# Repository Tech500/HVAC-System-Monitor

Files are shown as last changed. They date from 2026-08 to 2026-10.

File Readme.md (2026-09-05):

# HVAC System Monitor 

This repository contains a three‑node HVAC monitoring system designed as the successor to the Heating System Monitor IV project. It uses:

- LoRa Wake‑On‑Radio (WOR) for outdoor sensing
- ESP‑NOW for node‑to‑node communication
- Google Sheets for perpetual month‑to‑month and year‑to‑year logging

How blower detection works (variance-based thresholding): Blower state is detected with an MPU-6050 6-axis IMU attached to the outside of the blower enclosure. The sketch computes the statistical variance of accelerometer samples over a short window. A running blower produces mechanical vibration (high variance); a stopped blower produces almost none (low variance). Hysteresis between the ON and OFF thresholds prevents chatter at the transitions. No electrical hookup to the heating/cooling system is required, and no microphone is involved — it is immune to room noise.<br>

Logged data includes: NTP timestamp, outside temperature, inside temperature, inside humidity, thermostat setpoint, elapsed blower minutes (per cycle), daily total blower minutes, outside pressure, inside pressure, pressure difference (out − in), cycles today, coast minutes (hold time between cycles), and average cycle minutes.
Each record is written to both a local LittleFS log file and a perpetual Google Sheet (month-to-month, year-to-year).<br>

## Nodes

1. **WOR Sensor Node (Outdoor BME280)**  
   - SX1262 LoRa WOR RX  
   - BME280 outdoor readings  
   - ESP‑NOW TX → Receiver Node  

2. **Receiver Node (Indoor BME280 + Data collector + Google Sheets)**  
   - ESP‑NOW TX/RX (outdoor BME280 Node + Blower Node)  
   - Indoor BME280 readings  
   - Initiates WOR wake cycle  
   - Uploads combined HVAC data to Google Sheets  

3. **Blower Node (MPU6050 Vibration Sensing)**  
   - Detects blower ON/OFF via variance threshold, vibration  
   - ESP‑NOW TX → Receiver Node  
   - No electrical hookup to HVAC wiring
  
## Schematics and PCB Designs
The Schematics/ folder contains all hardware design files for the three‑node HVAC System Monitor.
All boards were designed in KiCad 10, and each PCB includes:

Full schematic (.kicad_sch)

PCB layout (.kicad_pcb)

Fabrication outputs (Gerber + drill files)

3D board previews (where applicable)

Supported Hardware Platforms
All PCBs in this project are designed around two specific ESP32‑S3 platforms:

Ebyte EoRa‑S3‑900TB  
A compact, battery‑optimized ESP32‑S3 + SX1262 LoRa module used for the WOR outdoor node and indoor receiver node.
Includes onboard battery charger, dual LDOs, SD slot, OLED header, and SX1262 radio — ideal for ultra‑low‑power sensing.

ESP32‑S3 SuperMini  
A minimal ESP32‑S3 module used for the Blower Node.
Provides a small footprint, simple power domain, and reliable ESP‑NOW performance for vibration sensing.

PCB Overview
The HVAC System Monitor requires three PCBs, corresponding to the three nodes:

ESP-NOW BME280 Node; with Wake-On-Radio (WOR) preamble (LoRa WOR + BME280)

ESP-NOW Indoor Node (BME280 + ESP‑NOW aggregator + Google Sheets uploader)

ESP-NOW Blower Node (MPU6050 vibration sensing + ESP‑NOW)

The ESP-NOW BME280 Node and ESP-NOW Inside Node use the same ESP‑NOW/BME280 PCB with GY-BME280-3.3V, 6 pin, built around the EoRa‑S3‑900TB.

The Blower Node uses a dedicated PCB built around the ESP32‑S3 SuperMini and the MPU6050 IMU.  
Note: not all ESP32-S3 SuperMini clones have the same pin layout!!!

PCB Designs Included
ESP-NOW BME280 Node and ESP‑NOW Blower Node

Single PCB design used for both ESP-NOW BME280 Node and ESP-NOW Inside Nodees

SX1262 LoRa WOR support (via EoRa-S3-900TB onboard SX1262 radio)

BME280 I²C header for GY-BME280-3.3V, 6 pin

EoRa-S3-900TB Battery‑optimized power domain

ESP‑NOW antenna layout

Mounting holes for outdoor enclosure use

ESP32‑S3 SuperMini Blower Node PCB

MPU6050 vibration sensor header

Vibration‑optimized mounting pattern

Simple 3.3V regulation

ESP‑NOW antenna layout

Compact footprint for blower, cabinet housing attachment
Note:  No electrical hook uprequired!

Fabrication Status
Gerber and drill files for all boards are included and ready for manufacturing.
The first batch of PCBs has been submitted and is currently awaiting delivery for hardware verification, fit‑testing, and firmware bring‑up.

## Folder Structure

```text
HVAC_System_Monitor/
│
├── BME280_Outside Node/
│   ├── BME280_WOR_Node.ino
│   ├── boards.h
│   ├── utilities.h
│   └── sx1262_commands.h
│  
│   
│
├── ESP-NOW_Inside_Node/
│   ├──  ESP-NOW_Inside_Node.ino  uses RadioLib library
|   ├── boards.h
│   └── utilities.h
│   
│
└── ESP-NOW_Blower_MPU6050/
    └──  ESP-NOW Blower_MPU6050ino

---

## Google Apps Script Setup

1. In Google Sheets, create a new Google Sheet.
2. Note the **Sheet ID** from the URL:
   `https://docs.google.com/spreadsheets/d/`**`<YOUR_SHEET_ID>`**`/edit`
3. Open the Script Editor: **Extensions → Apps Script**.
4. Delete the default `myFunction()` stub entirely.
5. Copy the full text contents of `Code.gs` from this repository.
6. Paste into the Script Editor.
7. Replace the placeholder Sheet ID in the script with the Sheet ID noted in Step 2.
8. **Save** (Ctrl+S or the save icon).
9. Click **Deploy → New Deployment**.
10. Select type: **Web App**.
11. Set **Execute as:** Me.
12. Set **Who has access:** Anyone.
13. Click **Authorize** → **Advanced** → click your Gmail account → **Allow**.
14. Copy the deployment ID and paste it into the Receiver sketch as the Google Script endpoint.

> **Note:** If you redeploy after changes, create a **New Deployment** each time and update
> the deployment ID in the Receiver sketch to match. (Editing an existing deployment to a
> new version can preserve the ID, but a fresh deployment always works.)

Numeric fields pass through a `numOrText()` helper in `Code.gs`: numbers are stored as
numbers, and the receiver's "Offline" sentinel (sent when the outdoor node fails to reply)
is preserved as text. Sheets functions like AVERAGE skip text cells automatically; in
pandas, load with `na_values=['Offline']`.

---

## Acknowledgements

This project was the result of a collaborative engineering effort involving both hands-on
experimentation and AI-assisted development. Each AI assistant contributed in different ways
throughout the project.

- **Claude** – Lead AI for all aspects of the project. Helped maintain technical focus,
  reviewed the evolving documentation for clarity and consistency, and provided extensive
  assistance in coding, organizing, and refining the final Markdown documentation.

- **Google Gemini** – Provided valuable guidance during the migration to **ESP32 Arduino
  Core 3.3.10**, helping identify and avoid legacy code patterns from earlier ESP32 core
  releases. Gemini also contributed to development discussions involving SX1262
  **Channel Activity Detection (CAD)**, Wake-on-Radio (WOR), and ESP32-S3 Deep Sleep
  integration.

- **ChatGPT** – Assisted throughout firmware development, debugging, architecture
  discussions, RadioLib integration, power optimization, Nordic PPK2 measurement
  interpretation, battery-life analysis, and technical review of the final documentation.

- **GitHub Copilot** – Assisted with firmware implementation, code completion, and
  day-to-day development within the programming environment.

- **Jan Gromeš** – Special thanks for the outstanding **RadioLib** library!

The successful implementation of an ESP32-S3 Deep Sleeping Wake-on-Radio node using the
SX1262 and RadioLib was made possible through this collaborative process. While the hardware
design, firmware integration, measurements, testing, and final engineering decisions were
performed by the author, the insights provided by each AI assistant significantly accelerated
development and helped improve the quality and accuracy of the final project.

*"Project not possible without everyone's help."*

## License

MIT License — see `LICENSE` for details.

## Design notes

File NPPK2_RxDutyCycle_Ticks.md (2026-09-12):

# SX1262 SetRxDutyCycle — Nordic PPK2 rxDutyCycle tick Observations

Power-profiling notes for `SetRxDutyCycle` (rxPeriod / sleepPeriod, in 15.625 µs ticks) on the SX1262, captured with a Nordic PPK2. 
Three experiment Images below, one per tick configuration tested.

### Nordic PPK II Observation Image 01

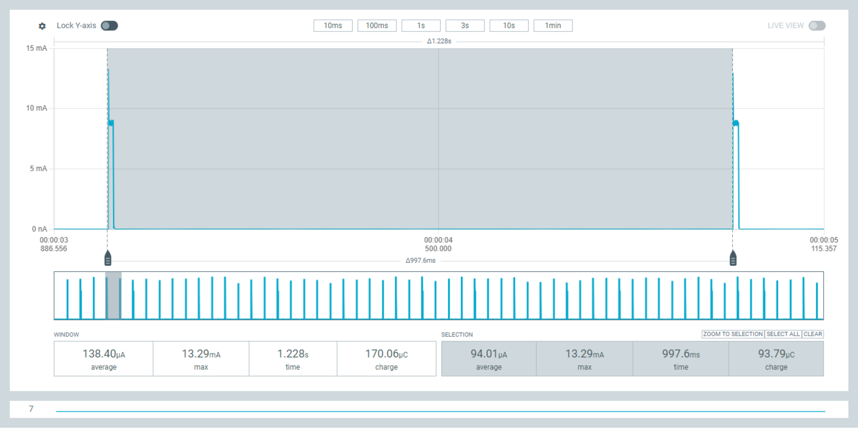
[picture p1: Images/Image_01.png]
Nordic PPK II --OneDutyCycle 01


#define RXDC_RX_TICKS       512UL  
#define RXDC_SLEEP_TICKS  63488UL  

| Metric | Value |
|---|---|
| Sleep average current | 22.40 µA |
| Duty-cycle average current | 94.01 µA |
| Peak current (RX window) | 13.29 mA |
| Wake event duration | 8.0 ms (per programmed rxPeriod) |
| Estimated battery life (3000 mAh) | ~43.7 months |

### Observations

- Selection window 997.6 ms, matching the programmed 1.000 s full cycle (8.0 ms RX + 992.0 ms sleep)
- By far the most efficient config measured — ~27× lower average current than Image 02, at the cost of a longer worst-case wake latency

---

### Nordic PPK II Observation Image 02

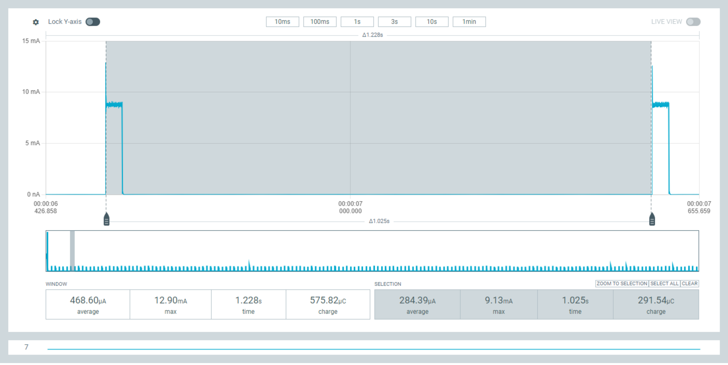
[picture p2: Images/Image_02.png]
Nordic PPK2 Observaton --OneDutyCycle 02


### Measurements

#define RXDC_RX_TICKS       2048UL  
#define RXDC_SLEEP_TICKS   64000UL  

| Metric | Value |
|---|---|
| Sleep average current | 21.94 µA  |
| Duty-cycle average current | 284.39 µA |
| Peak current (RX window) | 9.13 mA |
| Wake event duration | 32.0 ms (per programmed rxPeriod) |
| Estimated battery life (3000 mAh) | ~14.4 months |

### Observations

- Selection window 1.025 s, close to the programmed 1.032 s full cycle (32.0 ms RX + 1000.0 ms sleep)

---

### Nordic PPK II Observation Image 03

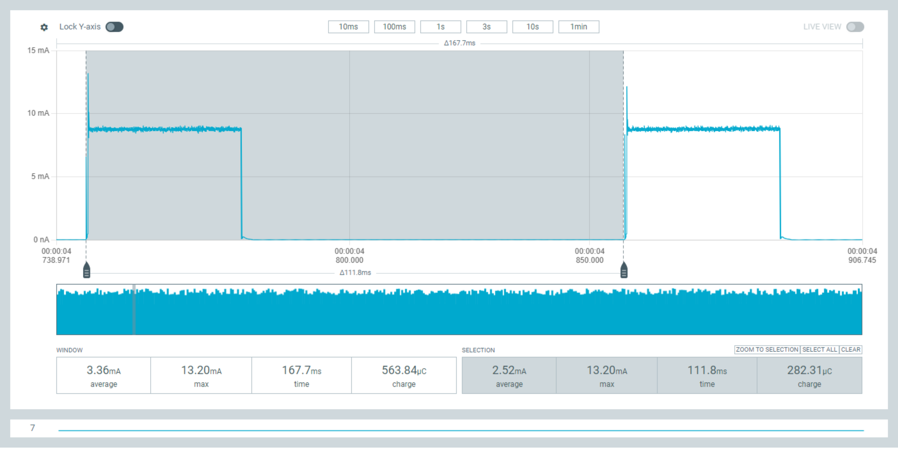
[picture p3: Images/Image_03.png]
Nordic PPK2 Observaton --OneDutyCycle 03


### Measurements

#define RXDC_RX_TICKS          1050UL  
#define RXDC_SLEEP_TICKS    5120UL  

| Metric | Value |
|---|---|
| Sleep floor current | ____ µA (not resolvable at this zoom level) |
| Duty-cycle average current | 2.52 mA |
| Peak current (RX window) | 13.20 mA |
| Wake event duration | 32.0 ms (per programmed rxPeriod) |
| Estimated battery life (3000 mAh) | ~1.6 months |

### Observations

- Selection window 111.8 ms, closely matching the programmed 112.0 ms full cycle (32.0 ms RX + 80.0 ms sleep)
- High average current (2.52 mA) driven by the 28.6% RX duty cycle — as expected, this is the least efficient config of the sweep

---

## Summary Comparison

| Image | Ticks (rxPeriod / sleepPeriod) | Duty-cycle avg (µA) | Est. battery life |
|---|---|---|---|
| 01 | 512 / 63488 | 94.01 | ~43.7 months |
| 02 | 2048 / 64000 | 284.39 | ~14.4 months |
| 03 |2048 / 5120 | 2520 | ~1.6 months |

### Conclusion

- Sleep period is the dominant lever, not RX period: Image 03 keeps the same 32 ms RX window as Image 02 but stretches sleep from 80 ms to 1000 ms, cutting average current ~9× (2520 µA → 284 µA)
- Shrinking the RX window matters too: Image 01 cuts RX from 32 ms to 8 ms on top of a comparable ~1 s sleep period, taking average current down another ~3× versus Image 03 (284 µA → 94 µA)
- Combined effect across the sweep so far: ~27× reduction in average current (2520 µA → 94 µA) and a projected battery-life improvement from ~1.6 months to ~43.7 months on a 3000 mAh cell
- Peak RX current stays roughly flat (9–13 mA) across all three configs — the gains come entirely from duty-cycle shaping, not from reducing per-window draw

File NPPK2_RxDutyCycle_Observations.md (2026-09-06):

# NPPK2 RxDutyCycle Observations — HVAC System Monitor (Outside Node)

Nordic PPK2 current captures of the outside node's register-level `SetRxDutyCycle` WOR cycle, including power-on init and a full WOR wake/transmit period.

## Power-On / EoRa Pi Init

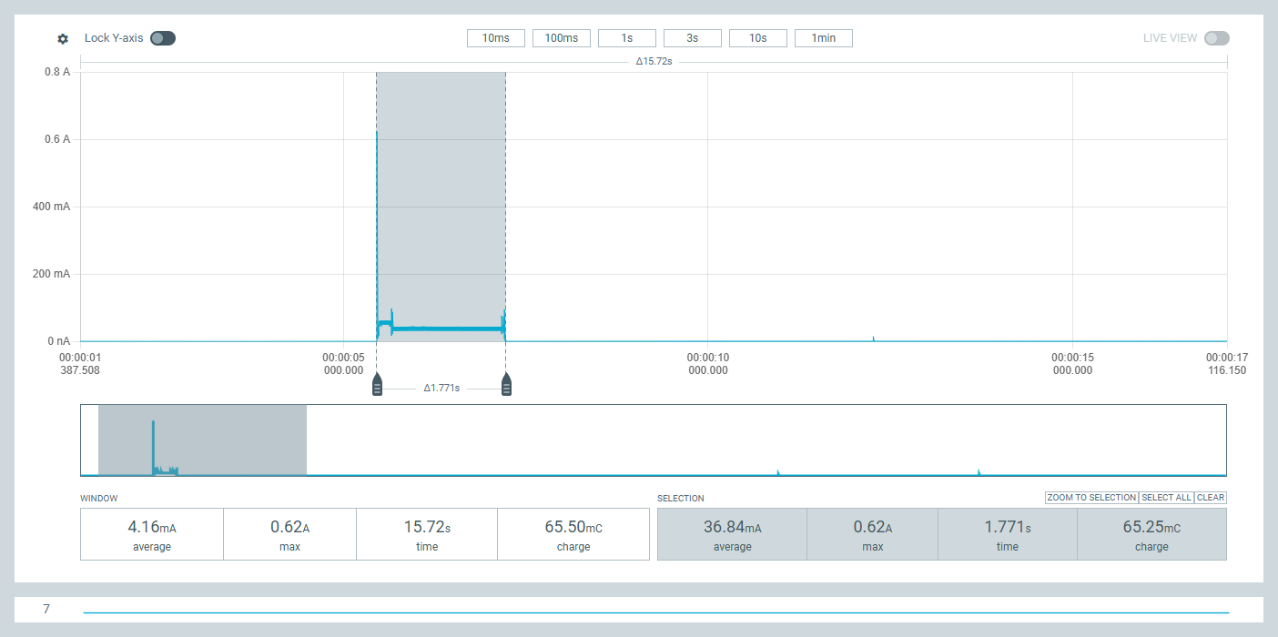
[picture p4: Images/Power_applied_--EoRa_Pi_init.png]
Power applied — EoRa-S3-900TB init
  

Capture from power application through radio/module initialization.

| Metric | Window (15.72 s) | Selection (1.771 s) |
|---|---|---|
| Average | 4.16 mA | 36.84 mA |
| Max | 0.62 A | 0.62 A |
| Charge | 65.50 mC | 65.25 mC |

## One Complete RxDutyCycle

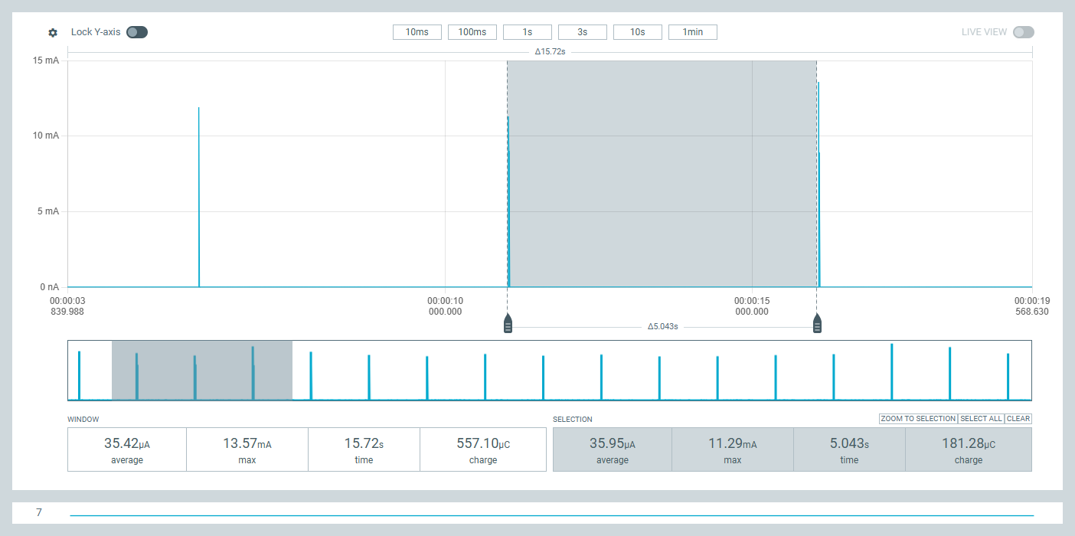
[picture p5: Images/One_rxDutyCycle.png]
One RxDutyCycle


Full active + sleep window for a single `SetRxDutyCycle` cycle.

| Metric | Window (15.72 s) | Selection (5.043 s) |
|---|---|---|
| Average | 35.42 µA | 35.95 µA |
| Max | 13.57 mA | 11.29 mA |
| Charge | 557.10 µC | 181.28 µC |

## Active (Rx) Segment

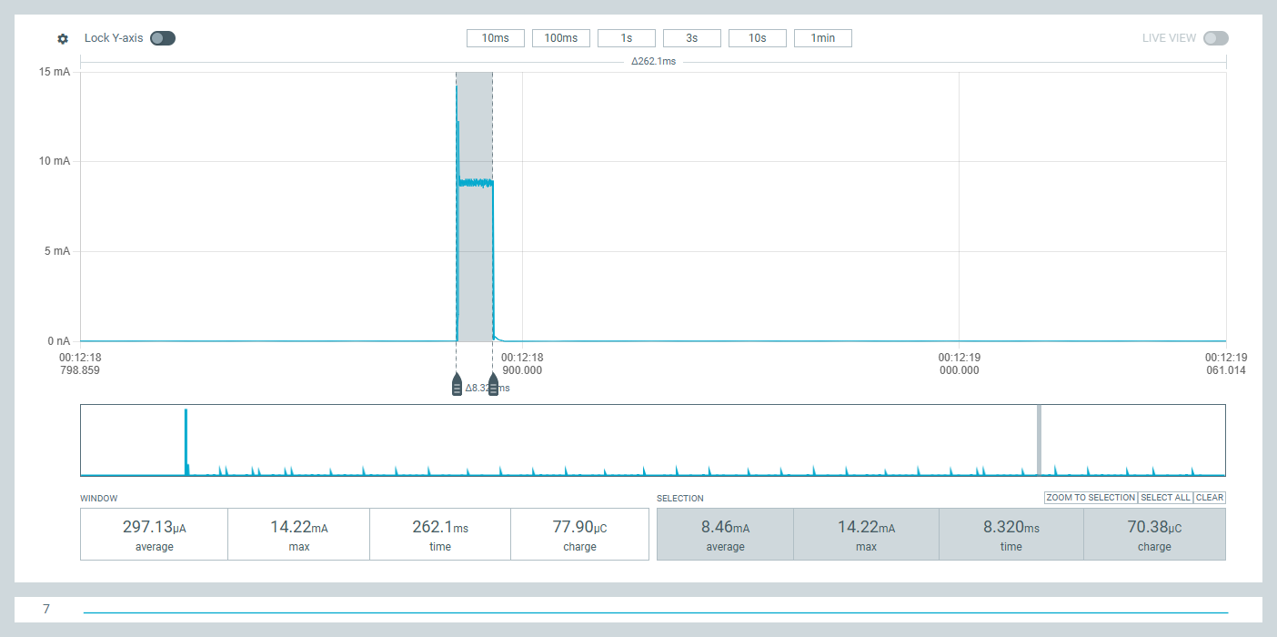
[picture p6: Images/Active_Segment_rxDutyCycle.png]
Active Segment RxDutyCycle


Zoomed view of the receive-active portion of the cycle.

| Metric | Window (262.1 ms) | Selection (8.320 ms) |
|---|---|---|
| Average | 297.13 µA | 8.46 mA |
| Max | 14.22 mA | 14.22 mA |
| Charge | 77.90 µC | 70.38 µC |

## Sleep Segment

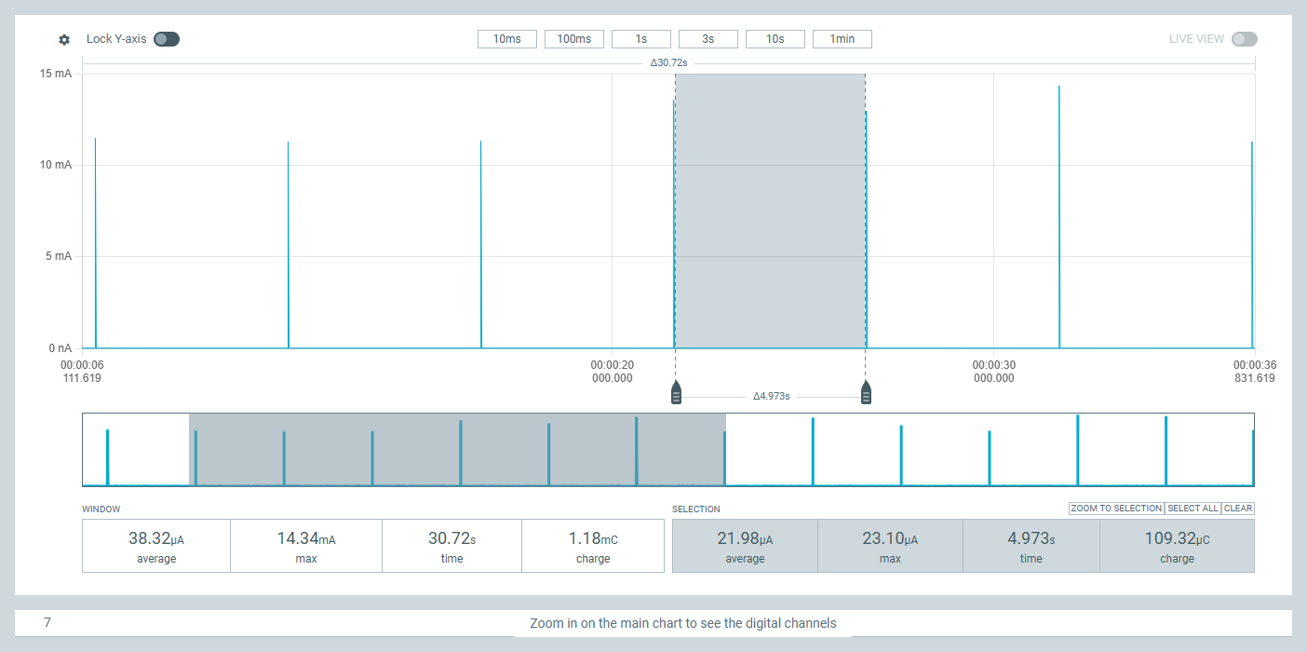
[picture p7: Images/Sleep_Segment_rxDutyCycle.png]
Sleep Segment RxDutyCycle


Zoomed view of the sleep portion between active windows.

| Metric | Window (30.72 s) | Selection (4.973 s) |
|---|---|---|
| Average | 38.32 µA | 21.98 µA |
| Max | 14.34 mA | 23.10 µA |
| Charge | 1.18 mC | 109.32 µC |

## WOR / ESP32-S3 Wake Period

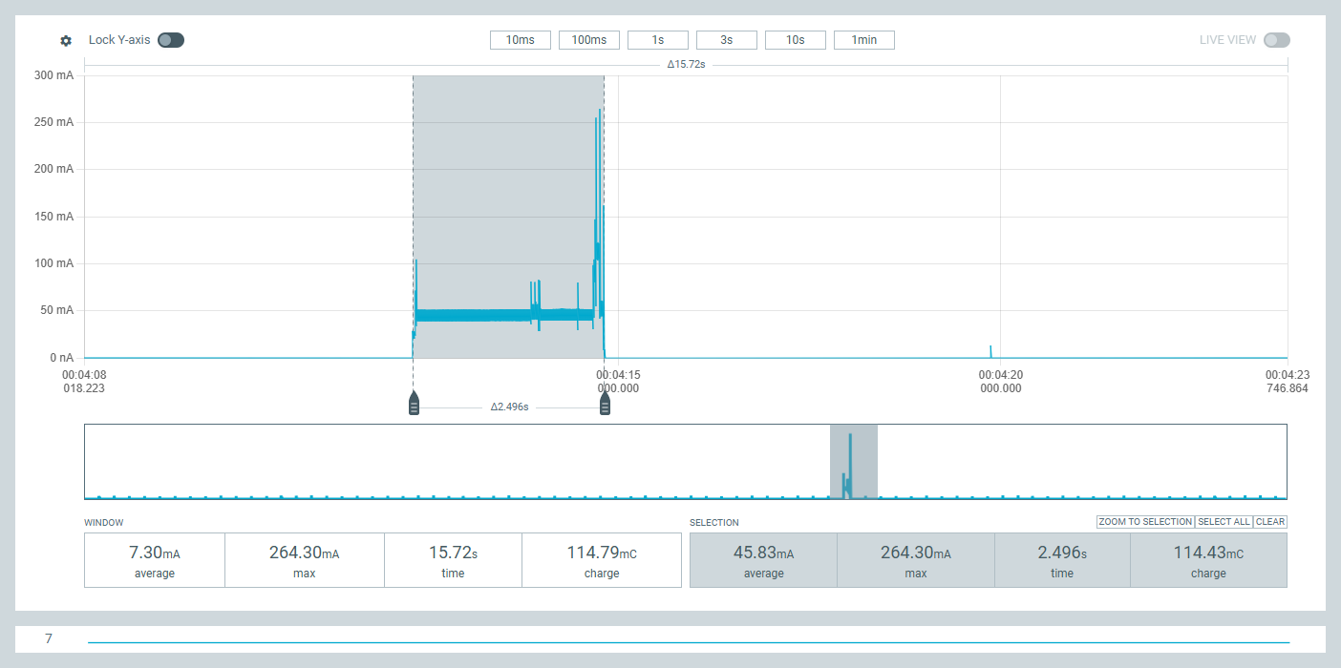
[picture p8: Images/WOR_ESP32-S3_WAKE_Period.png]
WOR ESP32-S3 Wake Period


Full wake event: EXT0 wakeup through BME280 read, ESP-NOW transmit, and re-arm into deep sleep.

| Metric | Window (15.72 s) | Selection (2.496 s) |
|---|---|---|
| Average | 7.30 mA | 45.83 mA |
| Max | 264.30 mA | 264.30 mA |
| Charge | 114.79 mC | 114.43 mC |

## Battery Life Estimate — MakerFocus 3000 mAh LiPo

Method: nameplate capacity ÷ average current, converted to months (÷ 24 h/day ÷ 30.44 days/month). No derating applied for self-discharge, regulator quiescent draw, or end-of-life voltage cutoff — treat as theoretical/upper-bound.

**Duty-cycle-only (no wake events), using this session's captures:**

| Source | Avg Current | Battery Life |
|---|---|---|
| One complete RxDutyCycle (window, sleep+active blended) | 35.42 µA | ~9.7 years (~116 months) |
| Isolated sleep-only floor (Sleep Segment *selection*, no active spike) | 21.98 µA | ~15.6 years (~187 months) |

Note: the Sleep Segment *window* (30.72 s, 38.32 µA avg, 14.34 mA max) isn't a clean sleep-only reading — its max shows it still contains active-pulse spikes, so it's really another blended full-cycle average and shouldn't be read as distinct from the row above. The 21.98 µA selection, with no spike in its max, is the actual isolated floor.

**With 20 WOR wake events/day (confirmed):** each wake (EXT0 → BME280 read → ESP-NOW TX → re-arm) costs ~114.4 mC (~0.0318 mAh), per the WOR wake-period capture above.

- Daily wake charge: 20 × 0.0318 mAh = 0.636 mAh/day
- Added average current: 0.636 mAh ÷ 24 h ≈ 26.5 µA
- Blended average: 35.42 µA (baseline duty cycle) + 26.5 µA (wake events) ≈ **61.9 µA**

| Figure | Value |
|---|---|
| Blended average current | ~61.9 µA |
| Battery life | ~2,020 days → **~66 months (~5.5 years)** |

This is the headline real-world figure for the repo — duty-cycle listening and the 20/day wake events contribute roughly equal shares to total drain.

## LoRa Config
```
  // Arguments: freq, bw, sf, cr, syncWord, power, preambleLength, tcxoVoltage, useRegulatorLDO
  int state = radio.begin(
    915.0,                              // Frequency: 915.0 MHz
    125.0,                              // Bandwidth: 125 kHz
    7,                                  // SF7
    5,                                  // CR 4/5 (Set to 5, NOT 7)
    RADIOLIB_SX126X_SYNC_WORD_PRIVATE,  // Resolves to 0x1424
    -1,                                 // Tx Power: 2 dBm
    5200,                               // WOR Preamble: 5000 symbols (~5.12s)
    0.0,                                // 0.0V = Crystal (XTAL), NOT TCXO!
    true                                // true = Use LDO Regulator Mode
  );
  
 ## ESP-Now BME280 Node, rxDutyCycle ticks
 
 #define RXDC_RX_TICKS       512UL     
 #define RXDC_SLEEP_TICKS 	323648UL

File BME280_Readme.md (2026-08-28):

# Ultra-Low-Power LoRa WOR BME280 Node

### SX1262 RxDutyCycle + EoRa-S3-900TB (ESP32-S3)

### *LoRa's only job is to wake the MCU.*

This open-source project demonstrates how to build an **ultra-low-power LoRa wake-on-radio receiver** using:

- The **built-in SX1262** LoRa transceiver on the EoRa-S3-900TB
- **RxDutyCycle** (Semtech Wake-On-Radio mode)
- **EXT0 deep-sleep wake**
- **One jumper wire**

The SX1262 periodically listens for a **LoRa preamble**.
If a preamble is detected, the radio asserts **DIO1**, waking the EoRa-S3-900TB from deep sleep.

**In this project, LoRa's only function is to wake the MCU.**
The SX1262 does not decode packets during RxDutyCycle — it simply detects the preamble and wakes the microcontroller.

This design is ideal for battery-powered sensors, remote monitors, and long-range low-power systems.

---

## What You Need

### Hardware

- **EoRa-S3-900TB** (ESP32-S3 low-power board with built-in SX1262)<br>
[EoRa-S3-900TB Development Board](https://ebyteiot.com/products/ebyte-oem-odm-eora-s3-900tb-22dbm-7km-mini-low-power-and-long-distance-sx1262-rf-module-lora-module-915mhz)
- **Two BME280 GY-BME280-3.3 Breakouts
- **One jumper wire** (GPIO33 → GPIO16)

### Required Files (must be in the sketch folder)

Place these **three files** in the same folder as your `.ino` or `main.cpp`:

| File | Purpose |
|---|---|
| `boards.h` | Ebyte board initBoard, board setup |
| `utilities.h` |Ebyte board, hardware mapping (DIO1 = GPIO33) |
| `SX1262_Commands.h` | Semtech low-level commands set (SetRxDutyCycle, IRQ ops, etc.) |

### Sketch Folder Placement

The entire sketch folder can be copied anywhere:

- Arduino sketchbook
- A custom project directory
- A local library folder

As long as these three files remain in the same folder as the sketch, the project will compile and run correctly.

### Mandatory Requirement

**ESP32 Arduino Core 3.3.10 is required!!!**

This project must be compiled using ESP32 Arduino Core 3.3.10. Earlier or later versions may:

- break EXT0 wake behavior
- Break ESP-NOW
- change RTC GPIO handling
- alter deep-sleep current
- modify SX1262 SPI timing
- cause WOR wake failures

Core 3.3.10 is the validated, stable version for the EoRa-S3-900TB + SX1262 WOR architecture.

---

## Wiring Overview

SX1262 is built into the EoRa-S3-900TB. All SX1262 connections (SPI, RESET, BUSY, DIO1) are already routed internally on the board. No external SX1262 wiring is required.

### Wake-On-Radio Jumper (Important)

The SX1262's DIO1 pin is internally routed to GPIO33 on the EoRa-S3-900TB.

But GPIO33 cannot wake the ESP32-S3 from deep sleep.

So we add one jumper wire:

**GPIO33 → GPIO16**

GPIO16 is RTC-capable and is used for EXT0 wake. This jumper is required for WOR wake.

---

## How RxDutyCycle Works

RxDutyCycle is a low-power receive mode built into the Semtech SX126x LoRa transceivers. Instead of staying in continuous receive, the radio periodically wakes up, opens a short listening window, and checks only for the presence of a LoRa preamble.

Semtech describes it as:

> "The receiver is activated periodically to detect the presence of a valid LoRa preamble."

### What the SX1262 does

1. Sleep
2. Wake periodically
3. Open RX window
4. Listen for LoRa preamble
5. If detected → assert DIO1
6. MCU wakes via EXT0
7. MCU reads and sends BME280 Readings to Inside Node via ESP-NOW
8. MCU re-arms RxDutyCycle and returns to sleep

### The Only Function of LoRa Here

In this project, LoRa is used only to wake the EoRa-S3-900TB. The SX1262 does not decode packets during RxDutyCycle — it simply detects the preamble and wakes the MCU.

---

## Firmware Wake Setup (EXT0 on GPIO16)

Wake pin is defined separately:

```cpp
#define WAKEUP_PIN GPIO_NUM_16
```

Before entering deep sleep, GPIO16 must be placed into the RTC domain:

```cpp
rtc_gpio_init(GPIO_NUM_16);
rtc_gpio_set_direction(GPIO_NUM_16, RTC_GPIO_MODE_INPUT_ONLY);
rtc_gpio_pulldown_en(GPIO_NUM_16);     
esp_sleep_enable_ext0_wakeup(GPIO_NUM_16, 1);   // or 0 depending on DIO1 polarity
```

If `rtc_gpio_init()` is missing, EXT0 will never wake the MCU.

---

## Power Profile (Three-Segment Model)
These values describe radio behavior only during the RxDutyCycle WOR pattern, measured using the Nordic PPK2 grey-selection box averages.

### Sleep Segment — WOR Sleep Portion

This is the radio's sleep portion inside the WOR cycle, not the SX1262 standalone deep-sleep mode.

- **Average: ~22.40 µA**
- This is the correct value from the Nordic PPK2 grey-selection box
- Any lower instantaneous readings (including single-digit µA) are not representative averages and must not be used for documentation

### Listening Segment — WOR RX Window

The radio opens its RX window and listens for a LoRa preamble.

- **Average: ~7.79 mA**
- Short duration (8.58 ms), autonomous listening on the SX1262

### One Complete RxDutyCycle **

This is the average of one RxDutyCycle:

- One complete RxDutyCycle (~94.01 µA Average, 997.8 ms) 
- Sleep portion (~22.40 µA, 987.9 ms)
- Listening window (~7.79 mA Average, 8.58 ms)
- RxDutyCycle pattern repeats continuously;
  accounting for the higher ~94.01 µA current.
- Wake current during each event-driven wake; during 24
  hours must also be added in the power profile.

[Nordic Power Profiler Kit 2 Observations](https://github.com/Tech500/HVAC-System-Monitor/blob/main/NPPK2_RxDutyCycle_Observations.md)

---

## EoRa-S3-900TB Wake Behavior (Event-Driven)

When WOR asserts DIO1:

1. The MCU wakes
2. Performs housekeeping
3. Reads SX1262 IRQ flags
4. Reads and sends BME280 reading
5. Re-arms WOR
6. Returns to deep sleep

Wake current is ~45.27 mA,  but only during the short wake window.

Typical deployments see ~20 wake events per day, so this cost is small and intermittent.

---

## Example Log Output

```
[WAKE] EXT0 Triggered by GPIO 16 (RTC Level: 1)
[WOR] Warm Boot active. SX1262 IRQ: 0x0004
BME280 -> Temp: 80.88 F  Hum: 54.18 %  Pres: 1017.4484 hPa
[ESP-NOW] Send to hub: OK
[ESP-NOW] Sent alertFlag: TRUE
Entering Deep Sleep with RxDutyCycle armed...

---

## Project Structure

```
/src
  * Node.ino
  boards.h
  utilities.h
  sx1262_commands.h
/docs
  images/
  timing/
```

---

## Contributions Welcome

This project is open-source and beginner-friendly. Contributions are welcome in:

- documentation
- timing diagrams
- SX1262 improvements
- deep-sleep optimization
- transmitter examples

---

## Summary

- SX1262 is built into the EoRa-S3-900TB
- SX1262 runs RxDutyCycle autonomously
- LoRa's only job is to wake the MCU
- DIO1 → GPIO33 → jumper → GPIO16 → EXT0 wake
- Three support files must be in the sketch folder
- Sketch folder can be placed anywhere
- ESP32 Core 3.3.10 is mandatory!!!
- WOR sleep segment averages ~22.40 µA
- Wake events are rare and efficient

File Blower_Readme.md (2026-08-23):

# Blower Node (MPU6050 Vibration Sensing + ESP‑NOW TX)

The Blower Node monitors HVAC blower state using an MPU6050 accelerometer attached to the blower housing. It detects ON/OFF cycles via vibration variance thresholds and sends state changes to the Receiver Node using ESP‑NOW.

## Features

- Safe, non‑electrical blower monitoring
- MPU6050 vibration sensing
- Variance‑based ON/OFF detection
- ESP‑NOW transmission to Receiver Node

## Files

- `Blower_Node.ino`  
- `boards.h`  
- `utilities.h`  
- `README.md`

## Year‑round tracking

Blower ON/OFF events are logged year‑round as part of the perpetual Google Sheets archive, enabling long‑term HVAC behavior analysis.

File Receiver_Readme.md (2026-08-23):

# Receiver Node (Indoor BME280 + ESP‑NOW Aggregator + Google Sheets)

The Receiver Node collects data from the WOR Sensor Node and Blower Node via ESP‑NOW, reads its own indoor BME280 sensor, merges all values, and uploads the result to Google Sheets.

## Features

- ESP‑NOW RX (outdoor BME280 + blower ON/OFF)
- Local indoor BME280 sensor
- Combines indoor + outdoor + blower state
- Uploads HVAC data to Google Sheets
- Perpetual month‑to‑month and year‑to‑year logging

## Files

- `Receiver_Node.ino`  
- `boards.h`  
- `utilities.h`  
- `README.md`

## Year‑round logging

Every record is appended to Google Sheets; an Apps Script can organize data by month and year, creating a multi‑year HVAC history.

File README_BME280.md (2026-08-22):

# Ultra-Low-Power LoRa WOR BME280 Node

### SX1262 RxDutyCycle + EoRa-S3-900TB (ESP32-S3)

### *LoRa's only job is to wake the MCU.*

This open-source project demonstrates how to build an **ultra-low-power LoRa wake-on-radio receiver** using:

- The **built-in SX1262** LoRa transceiver on the EoRa-S3-900TB
- **RxDutyCycle** (Semtech Wake-On-Radio mode)
- **EXT0 deep-sleep wake**
- **One jumper wire**

The SX1262 periodically listens for a **LoRa preamble**.
If a preamble is detected, the radio asserts **DIO1**, waking the EoRa-S3-900TB from deep sleep.

**In this project, LoRa's only function is to wake the MCU.**
The SX1262 does not decode packets during RxDutyCycle — it simply detects the preamble and wakes the microcontroller.

This design is ideal for battery-powered sensors, remote monitors, and long-range low-power systems.

---

## What You Need

### Hardware

- **EoRa-S3-900TB** (ESP32-S3 low-power board with built-in SX1262)<br>
[EoRa-S3-900TB Development Board](https://ebyteiot.com/products/ebyte-oem-odm-eora-s3-900tb-22dbm-7km-mini-low-power-and-long-distance-sx1262-rf-module-lora-module-915mhz)
- **Two BME280 GY-BME280-3.3 Breakouts
- **One jumper wire** (GPIO33 → GPIO16)

### Required Files (must be in the sketch folder)

Place these **three files** in the same folder as your `.ino` or `main.cpp`:

| File | Purpose |
|---|---|
| `boards.h` | Ebyte board pin definitions |
| `utilities.h` | SX1262 hardware mapping (DIO1 = GPIO33) |
| `SX1262_Commands.h` | Semtech low-level command set (SetRxDutyCycle, IRQ ops, etc.) |

### Sketch Folder Placement

The entire sketch folder can be copied anywhere:

- Arduino sketchbook
- A custom project directory
- A local library folder

As long as these three files remain in the same folder as the sketch, the project will compile and run correctly.

### Mandatory Requirement

**ESP32 Arduino Core 3.3.10 is required.**

This project must be compiled using ESP32 Arduino Core 3.3.10. Earlier or later versions may:

- break EXT0 wake behavior
- Break ESP-NOW
- change RTC GPIO handling
- alter deep-sleep current
- modify SX1262 SPI timing
- cause WOR wake failures

Core 3.3.10 is the validated, stable version for the EoRa-S3-900TB + SX1262 WOR architecture.

---

## Wiring Overview

SX1262 is built into the EoRa-S3-900TB. All SX1262 connections (SPI, RESET, BUSY, DIO1) are already routed internally on the board. No external SX1262 wiring is required.

### Wake-On-Radio Jumper (Important)

The SX1262's DIO1 pin is internally routed to GPIO33 on the EoRa-S3-900TB.

But GPIO33 cannot wake the ESP32-S3 from deep sleep.

So we add one jumper wire:

**GPIO33 → GPIO16**

GPIO16 is RTC-capable and is used for EXT0 wake. This jumper is required for WOR wake.

---

## How RxDutyCycle Works

RxDutyCycle is a low-power receive mode built into the Semtech SX126x LoRa transceivers. Instead of staying in continuous receive, the radio periodically wakes up, opens a short listening window, and checks only for the presence of a LoRa preamble.

Semtech describes it as:

> "The receiver is activated periodically to detect the presence of a valid LoRa preamble."

### What the SX1262 does

1. Sleep
2. Wake periodically
3. Open RX window
4. Look for LoRa preamble
5. If detected → assert DIO1
6. MCU wakes via EXT0
7. MCU reads and sends BME280 Readings to Inside Node via ESP-NOW
8. MCU re-arms RxDutyCycle and returns to sleep

### The Only Function of LoRa Here

In this project, LoRa is used only to wake the EoRa-S3-900TB. The SX1262 does not decode packets during RxDutyCycle — it simply detects the preamble and wakes the MCU.

---

## Firmware Wake Setup (EXT0 on GPIO16)

Wake pin is defined separately:

```cpp
#define WAKEUP_PIN GPIO_NUM_16
```

Before entering deep sleep, GPIO16 must be placed into the RTC domain:

```cpp
rtc_gpio_init(GPIO_NUM_16);
rtc_gpio_set_direction(GPIO_NUM_16, RTC_GPIO_MODE_INPUT_ONLY);
rtc_gpio_pulldown_en(GPIO_NUM_16);     
esp_sleep_enable_ext0_wakeup(GPIO_NUM_16, 1);   // or 0 depending on DIO1 polarity
```

If `rtc_gpio_init()` is missing, EXT0 will never wake the MCU.

---

## Power Profile (Three-Segment Model)
These values describe radio behavior only during the RxDutyCycle WOR pattern, measured using the Nordic PPK2 grey-selection box averages.

### Sleep Segment — WOR Sleep Portion

This is the radio's sleep portion inside the WOR cycle, not the SX1262 standalone deep-sleep mode.

- **Average: ~21 µA**
- This is the correct value from the Nordic PPK2 grey-selection box
- Any lower instantaneous readings (including single-digit µA) are not representative averages and must not be used for documentation

### Listening Segment — WOR RX Window

The radio opens its RX window and listens for a LoRa preamble.

- **Peak: ~14 mA**
- Short duration (30.22 ms), autonomous listening on the SX1262

### Complete RxDutyCycle Segment — One Full WOR Pattern

This is the average of the entire WOR cycle:

- Sleep portion (~21 µA)
- Listening window (~14 mA peak)
- Return to sleep

This full-cycle average is the correct representation of WOR behavior.

---

## EoRa-S3-900TB Wake Behavior (Event-Driven)

When WOR asserts DIO1:

1. The MCU wakes
2. Performs housekeeping
3. Reads SX1262 IRQ flags
4. Reads and sends BME280 reading
5. Re-arms WOR
6. Returns to sleep

Wake current is ~30 µA, but only during the short wake window.

Typical deployments see ~20 wake events per day, so this cost is small and intermittent.

---

## Example Log Output

```
Wakeup cause = 0
[COLD BOOT] Initializing SX1262 for RxDutyCycle WOR...

SX1262 reset...
SX1262 MINIMAL configuration complete.
Arming RxDutyCycle...
=== Entering deep sleep ===

Wakeup cause = 3
[WOR WAKE] EXT0 fired! Waiting for packet completion...
SX1262 IRQ = 0x0000
```

---

## Project Structure

```
/src
  main.cpp
  boards.h
  utilities.h
  sx1262_commands.h
/docs
  images/
  timing/
```

---

## Contributions Welcome

This project is open-source and beginner-friendly. Contributions are welcome in:

- documentation
- timing diagrams
- SX1262 improvements
- deep-sleep optimization
- transmitter examples

---

## Summary

- SX1262 is built into the EoRa-S3-900TB
- SX1262 runs RxDutyCycle autonomously
- LoRa's only job is to wake the MCU
- DIO1 → GPIO33 → jumper → GPIO16 → EXT0 wake
- Three support files must be in the sketch folder
- Sketch folder can be placed anywhere
- ESP32 Core 3.3.10 is mandatory
- WOR sleep segment averages ~21 µA
- Wake events are rare and efficient

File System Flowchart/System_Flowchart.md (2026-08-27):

# System Flowchart

1. Blower turns OFF
2. Blower Node detects vibration stop
3. Blower Node sends ESP-NOW flag + data to Inside Node
4. Inside Node receives packet
5. Inside Node sends WOR preamble
6. Outdoor SX1262 receives WOR and wakes ESP32-S3
7. Outdoor ESP32-S3 runs `setup()`
8. Reads wake reason EXT0 or Undefined
9. EXT0 Initializes SX1262 with no reset (Warm boot)
10. Undefined Initializes SX1262 with reset  (Cold boot)
11. Reads IRQ flags
12. Reads BME280
13. Sends ESP-NOW data to Inside Node
14. Arms RxDutyCycle
15. Returns to deep sleep

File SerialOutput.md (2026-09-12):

Serial Output of HVAC System Monitor; click to enlarge

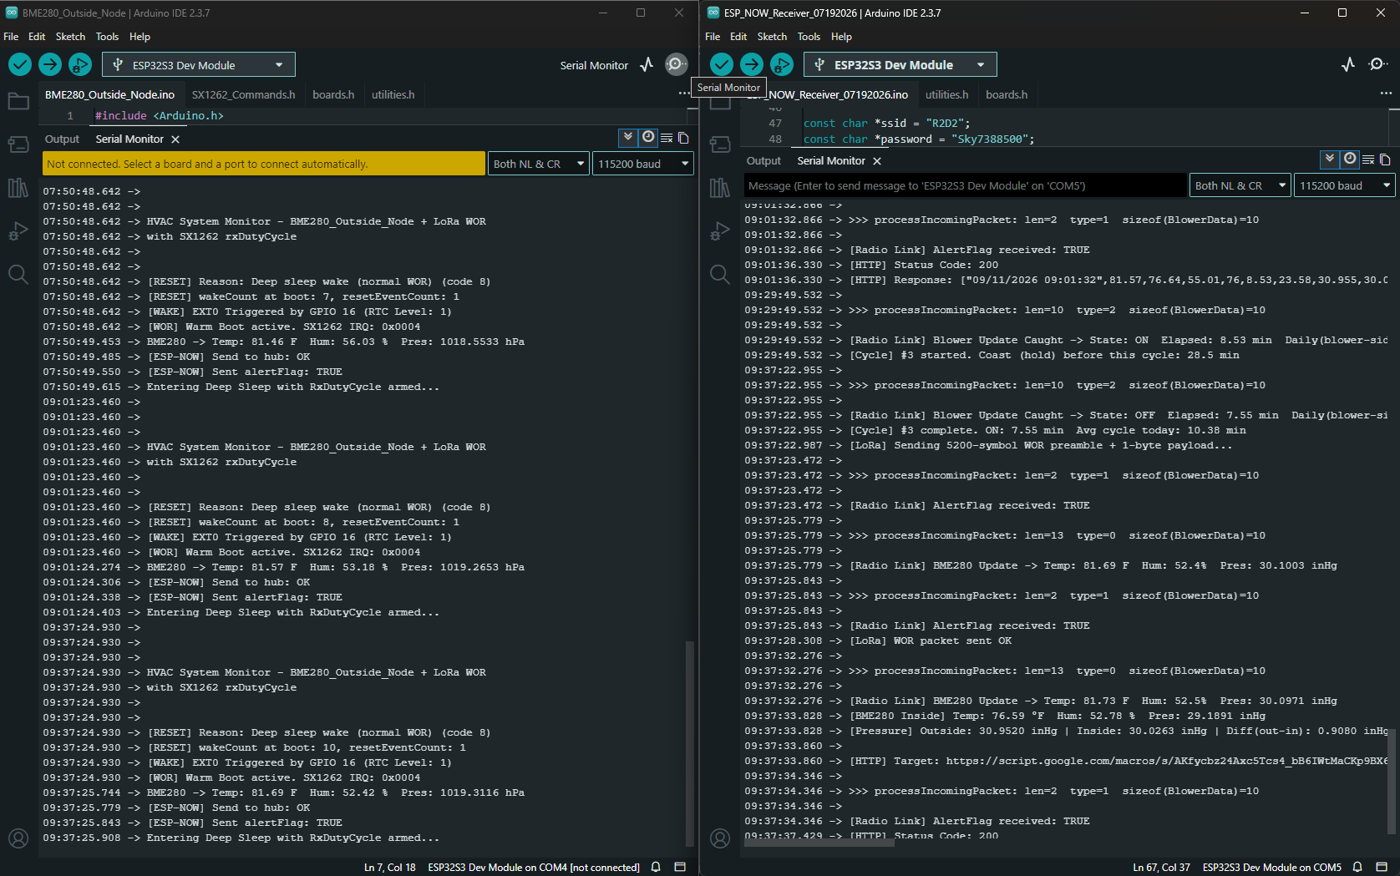
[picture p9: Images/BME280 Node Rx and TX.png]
BME280 Outside Node and Inside Node


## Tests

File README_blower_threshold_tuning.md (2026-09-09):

# Blower Detection — Threshold Tuning Guide

This sketch (`ESP_NOW_Blower_MPU6050.ino`) detects furnace blower ON/OFF
state from an MPU-6050 mounted on the blower housing, using the variance
of the accelerometer vector magnitude over a rolling sample window. It's
included here as a **reference/aid for tuning your own thresholds** —
the numeric values baked into this copy were measured on one specific
furnace and mount, and will almost certainly need to be re-measured for
yours.

## Why thresholds are per-installation

Variance readings depend on:

- **Mounting rigidity** — a loose or shifting sensor (e.g. duct tape
  starting to let go) introduces its own vibration/noise that has
  nothing to do with the blower, and will shift your baseline
  unpredictably. Mount the sensor as rigidly as you can before
  collecting tuning data, and re-tune if the mount changes.
- **Blower/furnace type** — direct-drive vs. belt-drive blowers,
  variable-speed vs. single-speed motors, and enclosure material all
  change the vibration signature and its magnitude.
- **Sensor orientation and placement** — where exactly on the housing
  it's mounted affects how strongly it picks up the blower's vibration
  vs. ambient building noise.

Because of this, treat every constant below as a **starting point to
verify on your own bench**, not a value to copy blindly.

## The four tunable constants

```cpp
const float ON_THRESHOLD    = 7000.0f;   // must rise above this to start counting toward ON
const float OFF_THRESHOLD   = 5000.0f;   // must drop below this to start counting toward OFF
const float SHOCK_CEILING   = 120000.0f; // sustained readings at/above this are treated as
                                          // shock/impact noise (stomping, drops), not blower
const int   ON_CONFIRM      = 3;         // consecutive over-threshold cycles before declaring ON
const int   OFF_CONFIRM     = 5;         // consecutive under-threshold cycles before declaring OFF
```

- **`ON_THRESHOLD` / `OFF_THRESHOLD`** form a hysteresis pair. Once the
  blower is OFF, variance must rise above `ON_THRESHOLD` to start
  counting toward ON; once ON, it must drop below `OFF_THRESHOLD` to
  start counting toward OFF. Readings between the two thresholds don't
  move either counter. The gap between them absorbs noise that would
  otherwise cause rapid ON/OFF/ON chatter if a single cutoff sat right
  at the boundary.
- **`SHOCK_CEILING`** excludes sustained high-variance events — a
  footstep, a stomp, something dropped near the sensor — from ever
  being counted as blower-ON, since those events can register far
  higher than the blower itself, and would otherwise satisfy
  `ON_CONFIRM` if they lasted long enough.
- **`ON_CONFIRM` / `OFF_CONFIRM`** are cycle counts, not seconds. One
  cycle = `SAMPLE_COUNT * SAMPLE_DELAY_MS` (default 64 samples × 5ms ≈
  320ms). Increase either if you see spurious transitions; a clean
  mechanical stop can usually use a low `OFF_CONFIRM`, while `ON_CONFIRM`
  may need to be a bit higher if your blower's spin-up is gradual
  rather than an abrupt jump in variance.

## How to collect your own numbers

1. Mount the sensor as rigidly as your install allows.
2. Flash this sketch as-is (the default thresholds are a reasonable
   starting point) and open the serial monitor, or poll `/status` over
   the network if WiFi is connected — both print live variance plus
   the current threshold/confirm values.
3. Log variance in each of these conditions for at least a minute
   each:
   - Blower fully OFF, ambient/quiet
   - Any nearby but unrelated vibration sources you expect in normal
     use (appliances, footsteps near the unit, etc.)
   - Blower ON, each speed/mode it runs at (e.g. heating fan-only vs.
     cooling, if your system has both)
   - A deliberate stomp or knock near the sensor, to see how high a
     real shock event reads on your hardware
4. Look for a **gap** between your highest OFF/ambient readings and
   your lowest ON readings. Put `OFF_THRESHOLD` a bit above the OFF
   ceiling and `ON_THRESHOLD` a bit below the ON floor, leaving margin
   on both sides.
5. Set `SHOCK_CEILING` above your highest legitimate ON reading but
   below your lowest observed shock reading. If those two ranges
   overlap on your hardware, the ceiling can't fully separate them —
   you may need a different mitigation (e.g. a longer `ON_CONFIRM`,
   since a stomp is usually much shorter than a real blower run).
6. Watch the serial log across a couple of real ON/OFF cycles once
   your furnace is actually running, and adjust `ON_CONFIRM` /
   `OFF_CONFIRM` if you see chatter or slow confirmation.

## Reference data (this install only)

Collected 07/01/2026, mounted furnace, not a general-purpose baseline:

| Condition | Variance range |
|---|---|
| OFF / quiet ambient | ~1,500 – 4,000 |
| Disposal running (10–15 ft) | ~2,000 – 4,600 (barely registers) |
| Footstep/stomp shocks | 130,000+ sustained |
| Blower ON, heating fan-only | ~4,500 – 9,500 |
| Blower ON, cooling mode | ~44,000 – 114,000 (higher fan speed) |

This is included only to show the *shape* of a working separation
(quiet vs. ON vs. shock) — not as a target to match on different
hardware.

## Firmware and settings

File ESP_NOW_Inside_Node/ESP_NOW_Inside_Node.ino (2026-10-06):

/* HVAC System Monitor
   ESP_NOW_Inside_Node.ino with temperature Offset + LoRa WOR trigger
   October 2, 2026 @ 2130 EDT
   ESP32 Core 3.3.10 Required!!!  Earlier Core wll break compile!!!
   Now runs on EoRa-S3-900TB (ESP32-S3 + onboard SX1262) -- same board
   as the BME280 Node.

*/

#include <Arduino.h>
#include <Wire.h>
#include <BME280I2C.h>
#include <WiFi.h>
#include <WiFiUdp.h>
#include <esp_wifi.h>
#include <ESP32_NOW.h>
#include "FS.h"
#include <LittleFS.h>
#include <FTPServer.h>
#include <WebServer.h>
#include <WiFiClientSecure.h>
#include <HTTPClient.h>
#include "rom/rtc.h"
#include "esp_system.h"  // esp_reset_reason() -- for reset_log.txt
#include <Preferences.h>

// ─── LoRa (EoRa-S3-900TB Pin defines) ─────────────────────────────────────
#define RADIO_SCLK_PIN              5
#define RADIO_MISO_PIN              3
#define RADIO_MOSI_PIN              6
#define RADIO_CS_PIN                7
#define RADIO_DIO1_PIN              33
#define RADIO_BUSY_PIN              34
#define RADIO_RST_PIN               8


#include <RadioLib.h>
#include <SPI.h>

float radioFreq = 915.0;
SX1262 radio = new Module(RADIO_CS_PIN, RADIO_DIO1_PIN, RADIO_RST_PIN, RADIO_BUSY_PIN);

#define WRITE_LED_PIN 23  //LittleFS Status LED  ON = Writing

const char *ssid = "ssid";
const char *password = "password";

//Flag to prevent reset
bool powerOnReset = false;

// ─── GOOGLE DEPLOYMENT ID ────────────────────────────────────────────────────
const String googleDeploymentID = "removed for security";
const String googleURL = "https://script.google.com/macros/s/" + googleDeploymentID + "/exec";

uint8_t masterAddress[] = { 0x1C, 0xDB, 0xD4, 0x85, 0x6E, 0x9C };
uint8_t senderBmeMAC[] = { 0xD0, 0xCF, 0x13, 0x0A, 0x48, 0x90 };
uint8_t senderBlowerMAC[] = { 0x9C, 0x13, 0x9E, 0xF2, 0x2A, 0xB4 };

#define HUB_WIFI_CHANNEL 11
#define CHANNEL 0

// ─────────────────────────────────────────────
// BME280 (Inside) — replaces MCP9808
// Default I2C address 0x76, same library as outside BME280 node
// ─────────────────────────────────────────────
BME280I2C bmeInside;

// I2C for inside BME280 -- explicit Wire.begin() on documented general-
// purpose header pins. GPIO17/18 (initBoard()'s I2C_SDA/I2C_SCL) are NOT
// on the main header per the pin mapping doc -- likely dedicated OLED
// connector pads, not reachable for external sensor wiring. GPIO42/41
// are confirmed general I/O, no radio/SD/strapping/RTC-wake conflicts.
// I2C for inside BME280 -- explicit setPins()/begin() on GPIO48/47.
// CONFIRMED WORKING via standalone BME280I2C test sketch: stable,
// consistent readings across many consecutive loops, no flicker.
// GPIO42/41 and GPIO40/39 were both intermittent on this board despite
// being valid, documented general-purpose pins.
#define SDA 47
#define SCL 48

// ─────────────────────────────────────────────
// BME280 (Outside) Temperature Calibration
// NOTE: offset includes steady-state self-heating of current
// always-on DevKit node. RE-CALIBRATE after EoRa deep-sleep
// migration -- self-heating term will largely disappear.
// ─────────────────────────────────────────────

// ─────────────────────────────────────────────
// BME280 (Inside) Temperature Calibration
// Offset applied to BME280 (inside) temperature output
// ─────────────────────────────────────────────
const float BME280_INSIDE_TEMP_CAL_OFFSET_F = +.90;

// ─── NTP / Time ──────────────────────────────────────────────────────────────
const char *udpAddress1 = "pool.ntp.org";
const char *udpAddress2 = "time.nist.gov";

int DOW, MONTH, DATE, YEAR, HOUR, MINUTE, SECOND;
String weekDay;
char strftime_buf[64];
String dtStamp = "";

String lastUpdate = "";
time_t tnow;

// Replace Ticker variables with global millis trackers
unsigned long lastResetCheck = 0;
const unsigned long checkInterval = 1000;  // Check every 1 second

// ─── Message / Packet Structures ─────────────────────────────────────────────
// ─── 1. Shared Message Types Enum ───────────────────────────────────────────
enum MessageType : uint8_t {
  MSG_BME280 = 0,
  MSG_ALERT_FLAG = 1,
  MSG_BLOWER_STATE = 2
};

// ─── 2. Receiver Packet Structures (Packed Byte Alignment) ──────────────────
struct __attribute__((packed)) BME280Data {
  MessageType type;   // 1 byte
  float temperature;  // 4 bytes
  float humidity;     // 4 bytes
  float pressure;     // 4 bytes (Total: 13 bytes)
};

struct __attribute__((packed)) AlertFlagPacket {
  MessageType type;  // 1 byte
  bool alert;        // 1 byte  (Total: 2 bytes)
};

struct __attribute__((packed)) BlowerData {
  MessageType type;         // 1 byte
  bool on;                  // 1 byte
  float elapsedMinutes;     // 4 bytes
  float dailyTotalMinutes;  // 4 bytes (Total: 10 bytes)
};

// ─── 3. Receiver Global Tracking Registers ──────────────────────────────────
bool alertFlag = false;  // Global state updated by MSG_ALERT_FLAG
volatile bool worCycleRequested = false;
bool blowerIsOn = false;  // Global state updated by MSG_BLOWER_STATE
float globalTemp = NAN;   // Global state updated by MSG_BME280
float globalHumidity = NAN;
float globalPressure = NAN;
bool sendWOR = false;


struct SensorRegisters {
  float outsideTemp;
  float insideTemp;
  float insideHumidity;
  float thermostat;
  float lastEventMinutes;
  float dailyTotalMinutes;
  float lastRecordedMinute;
  float outsidePressure;
  float insidePressure;
  float pressureDiffHPa;  // outsidePressure - insidePressure
};
SensorRegisters sensordata;

// ─── Peripherals ─────────────────────────────────────────────────────────────
FTPServer ftpSrv(LittleFS);
WebServer server(80);

// ─── ESP-NOW Peer Classes ─────────────────────────────────────────────────────

void processIncomingPacket(const uint8_t *data, int len);

// Blower node — receive only
class HeatingSenderPeer : public ESP_NOW_Peer {
public:
  HeatingSenderPeer(const uint8_t *mac_addr, uint8_t channel,
                    wifi_interface_t iface = WIFI_IF_STA,
                    const uint8_t *lmk = NULL)
    : ESP_NOW_Peer(mac_addr, channel, iface, lmk) {}

  bool add_to_system() {
    return ESP_NOW_Peer::add();
  }

protected:
  void onReceive(const uint8_t *data, size_t len, bool broadcast) override {
    processIncomingPacket(data, (int)len);
  }
};

// BME280 node — bidirectional (ESP-NOW reply path only now; wake trigger
// moved to LoRa WOR, see sendOutsideWakeRequest())

class BME280Peer : public ESP_NOW_Peer {
public:
  BME280Peer(const uint8_t *mac_addr, uint8_t channel,
             wifi_interface_t iface = WIFI_IF_STA,
             const uint8_t *lmk = NULL)
    : ESP_NOW_Peer(mac_addr, channel, iface, lmk) {}

  bool add_to_system() {
    return ESP_NOW_Peer::add();
  }

  bool remove_from_system() {
    return ESP_NOW_Peer::remove();
  }

  bool sendData(const uint8_t *data, size_t len) {
    return send(data, len);
  }

protected:
  void onReceive(const uint8_t *data, size_t len, bool broadcast) override {
    processIncomingPacket(data, (int)len);
  }
};

// Global instance if needed persistently
BME280Peer bmeNode(senderBmeMAC, CHANNEL, WIFI_IF_STA);

bool sendAlertFlagToReceiver(bool alertFlag) {
  AlertFlagPacket alertPacket = {};
  alertPacket.type = MSG_ALERT_FLAG;
  alertPacket.alert = alertFlag;

  bool result = bmeNode.sendData((uint8_t *)&alertPacket, sizeof(AlertFlagPacket));

  if (result) {
    Serial.printf("[ESP-NOW] Sent alertFlag: %s\n", alertFlag ? "TRUE" : "FALSE");
    Serial.println(alertFlag);
  } else {
    Serial.println(F("[ESP-NOW] Transmit failed"));
  }

  return result;
}

HeatingSenderPeer blowerNode(senderBlowerMAC, CHANNEL, WIFI_IF_STA);

// ─── Global Tracking Registers ───────────────────────────────────────────────
bool googleSheetsSent = false;

double elapsedMinutes = 0.0;
double dailyTotalMinutes = 0.0;

Preferences statePrefs;
const char *STATE_NAMESPACE = "hsm4state";

// ─── Cycle Tracking (thermostat optimization study) ──────────────────────────
bool prevBlowerIsOn = false;
int cyclesToday = 0;
time_t lastOffEpoch = 0;
double lastCoastMinutes = 0.0;
double avgCycleMinutes = 0.0;
float thermostatSetpoint = 75.0;

// ─── Elevation / Sea-Level Pressure Conversion ───────────────────────────────
#define STATION_ELEVATION_M 246.6

float toSeaLevelHPa(float absoluteHPa, float tempF) {
  float tempC = (tempF - 32.0) / 1.8;
  float tempK = tempC + 273.15;
  return absoluteHPa * exp(9.80665 * STATION_ELEVATION_M / (287.05 * tempK));
}

void sendGoogleSheetsData();
void sendDataToServer(String updateTime, float outT, float inT, float inHum,
                      float therm, double eventM, double dailyM,
                      float outP, float inP, float diffP);
void saveState();
bool restoreState();
void updateHeatingData();
void displayData();
void logData();
void disabledailyCooling();
void resetDailyStats();
void temperatureInterrupt();
void initNTP();
String getDateTime();
void logDailyTotal(String stamp, double dailyM, double eventM);
void logResetReason();
void initBME280Inside();
void readBME280Inside(float &tempF, float &humidity, float &pressureHPa);
String urlEncode(String str);
void setupLoRa();
void sendOutsideWakeRequest();

// ─── LoRa Setup (transmit-only on this node) ─────────────────────────────────
// Hub never listens over LoRa -- the outside node is the one sitting in
// startReceiveDutyCycleAuto(). All this node does is wake its own sleeping
// radio (implicit on any SPI transaction) and fire a WOR packet, then
// return to radio.sleep(). Link params MUST MATCH the outside node exactly.
void setupLoRa() {
  SPI.begin(RADIO_SCLK_PIN, RADIO_MISO_PIN, RADIO_MOSI_PIN);
  delay(1500);

  Serial.print(F("[SX126x] Initializing Hub Tx... "));

  // Arguments: freq, bw, sf, cr, syncWord, power, preambleLength, tcxoVoltage, useRegulatorLDO
  int state = radio.begin(
    915.0,                              // Frequency: 915.0 MHz
    125.0,                              // Bandwidth: 125 kHz
    7,                                  // SF7
    5,                                  // CR 4/5 (Set to 5, NOT 7)
    RADIOLIB_SX126X_SYNC_WORD_PRIVATE,  // Resolves to 0x1424
    -1,                                 // Tx Power: -1 dBm
    5200,                               // WOR Preamble: 5000 symbols (~5.12s)
    0.0,                                // 0.0V = Crystal (XTAL), NOT TCXO!
    true                                // true = Use LDO Regulator Mode
  );

  if (state == RADIOLIB_ERR_NONE) {
    Serial.println(F("success!"));
  } else {
    Serial.printf("failed, code %d\n", state);
  }

  radio.standby();
}

// Wake the sleeping radio (implicit via SPI) and transmit the WOR that
// wakes the outside node's ESP32 via DIO1 -> EXT0. Outside node's actual
// sensor reply still comes back over ESP-NOW (MSG_BME280), unchanged.
void sendOutsideWakeRequest() {
  radio.setPreambleLength(5200);
  Serial.println(F("[LoRa] Sending 5200-symbol WOR preamble + 1-byte payload..."));

  uint8_t payload = 0x55;
  int state = radio.transmit(&payload, 1);

  if (state == RADIOLIB_ERR_NONE) {
    Serial.println(F("[LoRa] WOR packet sent OK"));
    radio.standby();
  } else {
    Serial.printf("[LoRa] WOR send failed, code %d\n", state);
  }
  // no flag side effect here anymore
}

void sendTenWakeRequests() {

  const int NUM_WOR_TX = 10;
  const int DELAY_MS = 6000;

  radio.setPreambleLength(1200);

  Serial.println();
  Serial.println(F("========================================"));
  Serial.println(F("[LoRa] Starting 10 WOR transmissions"));
  Serial.println(F("========================================"));

  // 1-byte throw-away WOR payload
  uint8_t payload = 0x55;

  for (int i = 0; i < NUM_WOR_TX; i++) {

    Serial.printf(
      "[LoRa] WOR TX %d of %d START\n",
      i + 1,
      NUM_WOR_TX);

    // Blocking transmit:
    // returns only after the complete WOR packet is sent.
    int state = radio.transmit(&payload, 1);

    if (state == RADIOLIB_ERR_NONE) {
      Serial.printf(
        "[LoRa] WOR TX %d COMPLETE\n",
        i + 1);
    } else {
      Serial.printf(
        "[LoRa] WOR TX %d FAILED, code %d\n",
        i + 1,
        state);
    }
    while (DELAY_MS < 6000) {
      // Return to standby, then immediately begin next TX.
      radio.standby();
      return;
    }
  }
  Serial.println(F("[LoRa] All 10 WOR transmissions complete."));
  return;
}

// ─── NTP Init ────────────────────────────────────────────────────────────────
void initNTP() {
  configTime(0, 0, udpAddress1, udpAddress2);
  setenv("TZ", "EST+5EDT,M3.2.0/2,M11.1.0/2", 2);
  tzset();
  Serial.print("Waiting for first valid NTP timestamp");
  while (time(nullptr) < 100000ul) {
    Serial.print(".");
    delay(5000);
  }
  Serial.println("\nNTP Synchronized.");
}

// ─── Date/Time Stamp ─────────────────────────────────────────────────────────
String getDateTime() {
  tnow = time(nullptr) + 1;
  struct tm *ti = localtime(&tnow);
  DOW = ti->tm_wday;
  YEAR = ti->tm_year + 1900;
  MONTH = ti->tm_mon + 1;
  DATE = ti->tm_mday;
  HOUR = ti->tm_hour;
  MINUTE = ti->tm_min;
  SECOND = ti->tm_sec;
  strftime(strftime_buf, sizeof(strftime_buf), "%m/%d/%Y %H:%M:%S", localtime(&tnow));
  dtStamp = strftime_buf;
  return dtStamp;
}
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
void loop() {

  server.handleClient();

  ftpSrv.handleFTP();

  unsigned long currentMillis = millis();

  if (currentMillis - lastResetCheck >= checkInterval) {
    lastResetCheck = currentMillis;
    getDateTime();
  }

  static bool didMidnightReset = false;

  if (HOUR == 23 && MINUTE == 58) {
    if (!didMidnightReset) {
      digitalWrite(WRITE_LED_PIN, HIGH);

      double yesterdayDailyTotalMinutes = dailyTotalMinutes;
      double yesterdayElapsedMinutes = elapsedMinutes;

      Serial.printf("Midnight snapshot -> Elapsed: %.2f min  Daily: %.2f min  Cycles: %d  AvgCycle: %.2f min\n",
                    yesterdayElapsedMinutes, yesterdayDailyTotalMinutes,
                    cyclesToday, avgCycleMinutes);

      logDailyTotal(dtStamp, yesterdayDailyTotalMinutes, yesterdayElapsedMinutes);

      dailyTotalMinutes = 0;
      cyclesToday = 0;
      avgCycleMinutes = 0.0;
      saveState();
      Serial.println("Midnight reset: dailyTotalMinutes = 0, cyclesToday = 0 (NVS synced)");
      didMidnightReset = true;

      digitalWrite(WRITE_LED_PIN, LOW);
    }
  } else {
    didMidnightReset = false;
  }

  // ── Gatekeeper: alertFlag handler ────────────────────────────────────────
  if (alertFlag == true) {
    alertFlag = false;
    digitalWrite(WRITE_LED_PIN, HIGH);

    // LoRa WOR replaces the old ESP-NOW sendAlert()/delay(1000) poll --
    // the outside node is asleep between events now, so it can't answer
    // an ESP-NOW poll directly; it has to be woken via LoRa first.
    sendOutsideWakeRequest();

    // Outside node round trip: DIO1 wake -> ESP32 reboot -> setup() ->
    // radio init -> BME280 read -> WiFi reconnect -> ESP-NOW send. This
    // is meaningfully longer than the old always-on node's instant reply.
    // TODO: tune against measured round-trip time on the bench; this
    // blocks loop() (FTP, midnight check) for the full wait -- consider
    // converting to a non-blocking millis-based wait if that becomes a
    // problem in practice.
    delay(5000);  // starting point -- adjust once you've measured it

    float insideTempF = NAN, insideHumidity = NAN, insidePressureHPa = NAN;
    readBME280Inside(insideTempF, insideHumidity, insidePressureHPa);
    sensordata.insideTemp = insideTempF;
    sensordata.insideHumidity = insideHumidity;
    sensordata.outsideTemp = globalTemp;
    sensordata.thermostat = thermostatSetpoint;
    sensordata.outsidePressure = globalPressure;
    sensordata.insidePressure = insidePressureHPa;
    sensordata.pressureDiffHPa = globalPressure - insidePressureHPa;

    if (isnan(sensordata.outsideTemp)) {
      Serial.println("[BME280 Outside] No reply this cycle -- posting Offline.");
    }

    Serial.printf("[BME280 Inside] Temp: %.2f °F  Hum: %.2f %%  Pres: %.4f inHg\n",
                  insideTempF, insideHumidity, insidePressureHPa * 0.02953);
    Serial.printf("[Pressure] Outside: %.4f inHg | Inside: %.4f inHg | Diff(out-in): %.4f inHg\n",
                  toSeaLevelHPa(sensordata.outsidePressure, sensordata.outsideTemp) * 0.02953,
                  toSeaLevelHPa(sensordata.insidePressure, sensordata.insideTemp) * 0.02953,
                  sensordata.pressureDiffHPa * 0.02953);

    getDateTime();
    displayData();
    logData();
    sendGoogleSheetsData();
    googleSheetsSent = true;

    digitalWrite(WRITE_LED_PIN, LOW);
  }

  if (googleSheetsSent) {
    elapsedMinutes = 0;
    globalTemp = NAN;
    globalHumidity = NAN;
    globalPressure = NAN;
    googleSheetsSent = false;
  }
}

// ─── Google Sheets Bridge ─────────────────────────────────────────────────────
void sendGoogleSheetsData() {
  sendDataToServer(dtStamp,
                   sensordata.outsideTemp,
                   sensordata.insideTemp,
                   sensordata.insideHumidity,
                   thermostatSetpoint,
                   elapsedMinutes,
                   dailyTotalMinutes,
                   sensordata.outsidePressure,
                   sensordata.insidePressure,
                   sensordata.pressureDiffHPa);
}

void sendDataToServer(String updateTime, float outT, float inT, float inHum,
                      float therm, double eventM, double dailyM,
                      float outP, float inP, float diffP) {
  if (WiFi.status() != WL_CONNECTED) {
    Serial.println("\n\nSheet update blocked: Wi-Fi offline.");
    return;
  }

  WiFiClientSecure secureClient;
  secureClient.setInsecure();
  HTTPClient http;

  bool bmeOffline = isnan(outT);

  String outTStr = bmeOffline ? "Offline" : String(outT, 2);
  String outPStr = bmeOffline ? "Offline" : String(toSeaLevelHPa(outP, outT) * 0.02953, 4);
  String diffPStr = bmeOffline ? "Offline" : String(diffP * 0.02953, 4);

  String data = "?lastUpdate=" + urlEncode(updateTime)
                + "&outsideTemp=" + outTStr
                + "&insideTemp=" + String(inT, 2)
                + "&insideHumidity=" + String(inHum, 2)
                + "&thermostat=" + String(therm, 2)
                + "&elapsedMinutes=" + String(eventM, 2)
                + "&dailyTotalMinutes=" + String(dailyM, 2)
                + "&outsidePressure=" + outPStr
                + "&insidePressure=" + String(toSeaLevelHPa(inP, sensordata.insideTemp) * 0.02953, 4)
                + "&pressureDiff=" + diffPStr
                + "&cyclesToday=" + String(cyclesToday)
                + "&coastMinutes=" + String(lastCoastMinutes, 1)
                + "&avgCycleMinutes=" + String(avgCycleMinutes, 2);

  String urlFinal = googleURL + data;
  Serial.println("\n[HTTP] Target: " + urlFinal);

  if (http.begin(secureClient, urlFinal)) {
    http.addHeader("Content-Type", "application/x-www-form-urlencoded");
    http.setFollowRedirects(HTTPC_STRICT_FOLLOW_REDIRECTS);
    http.setTimeout(10000);
    int httpCode = http.GET();
    Serial.printf("[HTTP] Status Code: %d\n", httpCode);
    if (httpCode > 0) {
      Serial.println("[HTTP] Response: " + http.getString());
    } else {
      Serial.printf("[HTTP] Error: %s\n", http.errorToString(httpCode).c_str());
    }
    http.end();
  } else {
    Serial.println("\n Secure connection failed.");
  }
  alertFlag = false;
}

// ─── Local File Logging ───────────────────────────────────────────────────────
void logData() {
  if (!LittleFS.exists("/log.txt")) {
    File setupFile = LittleFS.open("/log.txt", FILE_WRITE);
    if (!setupFile) return;
    setupFile.println("Timestamp, OutsideTemp, InsideTemp, InsideHumidity, Setpoint, EventDuration, TotalRuntime, OutsidePressure_inHg, InsidePressure_inHg, PressureDiff_inHg, CyclesToday, CoastMin, AvgCycleMin");
    setupFile.close();
  }
  File appendLog = LittleFS.open("/log.txt", FILE_APPEND);
  if (!appendLog) return;

  bool bmeOffline = isnan(sensordata.outsideTemp);

  appendLog.print(dtStamp);
  appendLog.print(" , Outside: ");
  if (bmeOffline) appendLog.print("Offline");
  else appendLog.print(sensordata.outsideTemp, 2);
  appendLog.print(" F, Inside: ");
  appendLog.print(sensordata.insideTemp, 2);
  appendLog.print(" F, In.Humidity: ");
  appendLog.print(sensordata.insideHumidity, 2);
  appendLog.print(" %, Thermostat: ");
  appendLog.print(thermostatSetpoint, 2);
  appendLog.print(" F, Event: ");
  appendLog.print(sensordata.lastEventMinutes, 2);
  appendLog.print(", Total 24HR: ");
  appendLog.print(sensordata.dailyTotalMinutes, 2);
  appendLog.print(", OutP: ");
  if (bmeOffline) appendLog.print("Offline");
  else appendLog.print(toSeaLevelHPa(sensordata.outsidePressure, sensordata.outsideTemp) * 0.02953, 4);
  appendLog.print(" inHg, InP: ");
  appendLog.print(toSeaLevelHPa(sensordata.insidePressure, sensordata.insideTemp) * 0.02953, 4);
  appendLog.print(" inHg, Diff: ");
  if (bmeOffline) appendLog.print("Offline");
  else appendLog.print(sensordata.pressureDiffHPa * 0.02953, 4);
  appendLog.print(" inHg, Cycles: ");
  appendLog.print(cyclesToday);
  appendLog.print(", Coast: ");
  appendLog.print(lastCoastMinutes, 1);
  appendLog.print(" min, AvgCycle: ");
  appendLog.print(avgCycleMinutes, 2);
  appendLog.print(" min\n");
  appendLog.close();
}

void logDailyTotal(String stamp, double dailyM, double eventM) {
  if (!LittleFS.exists("/daily_totals.csv")) {
    File setupFile = LittleFS.open("/daily_totals.csv", FILE_WRITE);
    if (!setupFile) return;
    setupFile.println("Timestamp,DailyTotalMinutes,LastEventMinutes,CyclesToday,AvgCycleMinutes");
    setupFile.close();
  }
  File appendLog = LittleFS.open("/daily_totals.csv", FILE_APPEND);
  if (!appendLog) return;
  appendLog.print(stamp);
  appendLog.print(",");
  appendLog.print(dailyM, 2);
  appendLog.print(",");
  appendLog.print(eventM, 2);
  appendLog.print(",");
  appendLog.print(cyclesToday);
  appendLog.print(",");
  appendLog.println(avgCycleMinutes, 2);
  appendLog.close();
}
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

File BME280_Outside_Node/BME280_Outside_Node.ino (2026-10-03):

/* HVAC System Monitor
   BME280_Outside_Node.ino with temperature Offset + ESP-NOW + LoRa WOR trigger
   October 2, 2026 @ 2130 EDT
   ESP32 Core 3.3.10 Required!!!  Earlier Core wll break compile!!!
   Now runs on EoRa-S3-900TB (ESP32-S3 + onboard SX1262) -- same board
   as the BME280 Node.

*/

#include <Arduino.h>
#include <SPI.h>
#include <Wire.h>
#define EoRa_PI_V1
#include <boards.h>
#include "SX1262_commands.h"
#include <WiFi.h>
#include <ESP32_NOW.h>
#include <esp_now.h>
#include <esp_wifi.h>
#include <BME280I2C.h>
#include <esp_sleep.h>
#include "driver/rtc_io.h"
#include "rom/rtc.h"
#include "esp_system.h"
#include "esp_private/periph_ctrl.h"

#define WAKEUP_PIN GPIO_NUM_16

#define BOARD_LED 37
#define LED_ON HIGH
#define LED_OFF LOW

#define BME_SDA_PIN 47
#define BME_SCL_PIN 48
#define BME_I2C_ADDR 0x76

#define RXDC_RX_TICKS       512UL     
#define RXDC_SLEEP_TICKS 	323648UL    

uint8_t hubMAC[] = { 0x1C, 0xDB, 0xD4, 0x85, 0x6E, 0x9C };

uint8_t HUB_WIFI_CHANNEL = 11;
uint8_t CHANNEL = 0;

#define BME_SDA 47
#define BME_SCL 48

// Flag stored in low-power RTC SRAM (survives ESP32 deep sleep)
RTC_DATA_ATTR bool sxConfigured = false;
RTC_DATA_ATTR uint32_t wakeCount = 0;

const float BME280_OUTSIDE_TEMP_CAL_OFFSET_F = +5.54;
const float STATION_ELEVATION_FT = 791.0f;
const float STATION_ELEVATION_M = STATION_ELEVATION_FT * 0.3048f;

BME280I2C bme;

// ─── Struct Definitions ───
enum MessageType : uint8_t {
  MSG_BME280 = 0,
  MSG_ALERT_FLAG = 1,
  MSG_BLOWER_STATE = 2
};

struct __attribute__((packed)) AlertFlagPacket {
  MessageType type;
  bool alert;
};

struct __attribute__((packed)) BlowerData {
  MessageType type;
  bool on;
  float elapsedMinutes;
  float dailyTotalMinutes;
};

struct __attribute__((packed)) BME280Data {
  MessageType type;
  float temperature;
  float humidity;
  float pressure;
};

// ─── 3. Receiver Global Tracking Registers ──────────────────────────────────
bool alertFlag = false;          // Global state updated by MSG_ALERT_FLAG
bool blowerIsOn = false;         // Global state updated by MSG_BLOWER_STATE
float globalTemp = NAN;          // Global state updated by MSG_BME280
float globalHumidity = NAN;
float globalPressure = NAN;

class HubPeer : public ESP_NOW_Peer {
public:
  HubPeer(const uint8_t *hubMAC, uint8_t CHANNEL)
    : ESP_NOW_Peer(hubMAC, CHANNEL, WIFI_IF_STA, NULL) {}

  bool add_to_system() {
    return ESP_NOW_Peer::add();
  }
  bool remove_from_system() {
    return ESP_NOW_Peer::remove();
  }
  bool sendData(const uint8_t *data, size_t len) {
    return send(data, len);
  }
};

// -------------------------------------------------------------
// TRANSMIT ALERT FLAG TO HUB VIA ESP-NOW
// -------------------------------------------------------------
bool sendAlertFlagToReceiver(bool alertFlag) {
  // 1. Ensure STA mode is active
  WiFi.mode(WIFI_STA);

  // 2. Fetch or assign a valid primary channel (1-14)
  uint8_t primaryChannel = WiFi.channel();
  if (primaryChannel == 0) primaryChannel = HUB_WIFI_CHANNEL > 0 ? HUB_WIFI_CHANNEL : 1;
  
  esp_wifi_set_channel(primaryChannel, WIFI_SECOND_CHAN_NONE);

  if (!ESP_NOW.begin()) {
    Serial.println(F("[ESP-NOW] Engine start failed"));
    return false;
  }

  // 3. Create peer instance on valid primary channel
  HubPeer localHub(hubMAC, primaryChannel);

  // 4. Force-purge any lingering table registration for this MAC
  localHub.remove_from_system();

  // 5. Register peer
  if (!localHub.add_to_system()) {
    Serial.printf("[ESP-NOW Error] Peer add failed on Ch %d. Check hubMAC array.\n", primaryChannel);
    ESP_NOW.end();
    return false;
  }

  // 6. Send payload
  AlertFlagPacket alertPacket = {};
  alertPacket.type = MSG_ALERT_FLAG;
  alertPacket.alert = alertFlag;

  bool result = localHub.sendData((uint8_t *)&alertPacket, sizeof(AlertFlagPacket));

  if (result) {
    Serial.printf("[ESP-NOW] Sent alertFlag: %s\n", alertFlag ? "TRUE" : "FALSE");
  } else {
    Serial.println(F("[ESP-NOW] Transmit failed"));
  }

  // 7. Cleanup
  localHub.remove_from_system();
  ESP_NOW.end();

  return result;
}

float relativePressure(float stationPressureHPa, float elevationMeters) {
  return stationPressureHPa / pow(1.0f - (elevationMeters / 44330.0f), 5.255f);
}

bool readAndSendBME280() {
  Wire.end();
  delay(50);
  Wire.setPins(BME_SDA, BME_SCL);
  if (!Wire.begin(BME_SDA, BME_SCL)) {
    Serial.println(F("Failed to allocate I2C peripheral instance!"));
  }
  delay(50);

  if (!bme.begin()) {
    Serial.println(F("BME280 not found -- check wiring/address"));
    return false;
  }

  float tempF = NAN, humidity = NAN, pressureHPa = NAN;
  BME280::TempUnit tempUnit(BME280::TempUnit_Fahrenheit);
  BME280::PresUnit presUnit(BME280::PresUnit_hPa);

  delay(500);

  bme.read(pressureHPa, tempF, humidity, tempUnit, presUnit);
  tempF += BME280_OUTSIDE_TEMP_CAL_OFFSET_F;

  delay(200);

  if (isnan(tempF) || isnan(pressureHPa)) {
    Serial.println(F("Error reading BME280 telemetry."));
    return false;
  }

  float relPressureHPa = relativePressure(pressureHPa, STATION_ELEVATION_M);

  Serial.printf("BME280 -> Temp: %.2f F  Hum: %.2f %%  Pres: %.4f hPa\n",
                tempF, humidity, relPressureHPa);

  return sendTelemetryViaESPNOW(tempF, humidity, relPressureHPa);
}

bool sendTelemetryViaESPNOW(float tempF, float humidity, float pressureHPa) {
  WiFi.mode(WIFI_STA);
  WiFi.disconnect();

  esp_wifi_set_channel(HUB_WIFI_CHANNEL, WIFI_SECOND_CHAN_NONE);

  if (!ESP_NOW.begin()) {
    Serial.println(F("ESP-NOW init failed"));
    WiFi.mode(WIFI_OFF);
    return false;
  }

  HubPeer localHub(hubMAC, HUB_WIFI_CHANNEL);
  if (!localHub.add_to_system()) {
    Serial.println(F("Failed to bind hub peer"));
    ESP_NOW.end();
    WiFi.mode(WIFI_OFF);
    return false;
  }

  BME280Data pkt;
  pkt.type = MSG_BME280;
  pkt.temperature = tempF;
  pkt.humidity = humidity;
  pkt.pressure = pressureHPa;

  bool sent = localHub.sendData((uint8_t *)&pkt, sizeof(BME280Data));
  Serial.printf("[ESP-NOW] Send to hub: %s\n", sent ? "OK" : "FAILED");

  localHub.remove_from_system();
 
  return sent;
}

#define BENCH_TESTING 1

void preparePinsForSleep() {
  digitalWrite(RADIO_CS_PIN, HIGH);
  gpio_hold_en((gpio_num_t)RADIO_CS_PIN);

  pinMode(RADIO_RST_PIN, INPUT);
  gpio_hold_en((gpio_num_t)RADIO_RST_PIN);

#if !BENCH_TESTING
  Serial.flush();
  periph_module_disable(PERIPH_USB_MODULE);

  pinMode(GPIO_NUM_19, INPUT);
  pinMode(GPIO_NUM_20, INPUT);
  gpio_pullup_dis(GPIO_NUM_19);
  gpio_pulldown_dis(GPIO_NUM_19);
  gpio_pullup_dis(GPIO_NUM_20);
  gpio_pulldown_dis(GPIO_NUM_20);
  gpio_hold_en(GPIO_NUM_19);
  gpio_hold_en(GPIO_NUM_20);
#endif

  gpio_deep_sleep_hold_en();
}

void releasePinHoldsOnWake() {
  gpio_deep_sleep_hold_dis();

  gpio_hold_dis((gpio_num_t)RADIO_CS_PIN);
  gpio_hold_dis((gpio_num_t)RADIO_RST_PIN);
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

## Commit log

2026-08-22 Fix section title and update wake behavior steps
    Corrected the title of the Power Profile section and updated the wake behavior steps for clarity.
2026-08-22 Update RX window power consumption details
    Clarified the description of the RX window's power consumption.
2026-08-22 Update README to correct re-arm terminology
2026-08-23 Refactor comments in ESP_NOW_Inside_Node.ino
    Updated comments for clarity and corrected formatting issues.
    [ESP_NOW_Inside_Node.ino]
2026-08-23 Refactor BME280 Outside Node code for clarity
    Updated comments and variable names for clarity. Changed pressure calculation to use relative pressure based on station elevation.
2026-08-24 Update project title in Readme.md
    Removed 'Successor to Heating System Monitor IV' from title.
2026-08-26 Refactor ESP_NOW_Inside_Node.ino for clarity and updates
    Updated comments and code structure for clarity and consistency. Adjusted LoRa parameters and fixed variable definitions.
    [ESP_NOW_Inside_Node.ino]
2026-08-26 Improve Serial output formatting and add delay
    Updated Serial print statements for better formatting and added a delay before sending Google Sheets data.
2026-08-26 Update ESP_NOW_Inside_Node
    Corrections to sending data to Google Sheet.
    [ESP_NOW_Inside_Node.ino]
2026-08-26 Rename ESP32-S3 WOR EXT0 Wakeup.png to WOR EXT0 Wakeup.png
2026-08-26 Update EXT0 to ESP32-S3 in WOR section
2026-08-27 Revise power consumption details in BME280_Readme.md
    Updated power consumption values and clarified wake current details in the README.
2026-08-27 Update current values and section title in README
    Corrected the average current value for the RX window and fixed the section title formatting.
2026-08-27 Rename ESP-NOW Receiver Node Schematic.png to ESP-NOW Inside Node Schematic.png
2026-08-27 Revise ESP32 core requirement and log output
    Updated mandatory requirement emphasis and corrected average current consumption value. Modified example log output for clarity.
2026-08-27 Update sleep portion current value in documentation
2026-08-27 Update WOR sleep segment average current consumption
2026-08-27 Fix formatting in System Flowchart markdown
2026-08-27 Fix formatting and renumber steps in flowchart
2026-08-27 Fix numbering in System Flowchart steps
2026-09-03 Enhance Readme with PCB and hardware details
    Expanded details on PCB designs and supported hardware platforms for the HVAC System Monitor. Updated folder structure and fabrication status information.
2026-09-03 Revise PCB names in Readme.md
    Updated PCB names for consistency and clarity.
2026-09-09 Enhance blower detection and data persistence
    Updated NVS persistence for dailyTotalMinutes to prevent data loss during power changes. Added shock ceiling filter to improve blower detection accuracy and modified FTP handling to reduce timeouts.
    [ESP_NOW_Blower_MPU6050.ino]
2026-09-09 Fix formatting in ESP_NOW_Blower_MPU6050.ino comments
    [ESP_NOW_Blower_MPU6050.ino]
2026-09-09 Implement reset reason capture and logging
    Added reset-reason capture and logging for diagnostics, including a human-readable reset reason function.
    [BME280_Outside_Node.ino]
2026-09-11 Fix logging and update serial baud rate
    Updated serial baud rate and improved logging functionality.
    [ESP_NOW_Blower_MPU6050.ino]
2026-09-11 Update comments to specify ESP32 Core requirement
    Added a note about required ESP32 Core version to avoid compile issues.
    [ESP_NOW_Blower_MPU6050.ino]
2026-09-29 Corrected pcb I2C SDA and SCL
    Updated I2C pins, modified logging behavior, and improved reset reason logging. Adjusted thresholds and added changes to the change log.
    [ESP_NOW_Blower_MPU6050.ino]
2026-10-01 Remove BOARD_LED definition from BME280_Outside_Node.ino
2026-10-03 Refactor comments and define LoRa radio pins
    Updated comments and pin definitions for LoRa radio.
2026-10-03 Update I2C pins for MPU-6050 configuration
2026-10-03 Reset dailyTotalMinutes if out of range
    Add validation for dailyTotalMinutes from NVS.
    [ESP_NOW_Blower_MPU6050.ino]
2026-10-06 Remove sensitive Google Deployment ID
    Replaced sensitive Google Deployment ID with a placeholder for security.
    [ESP_NOW_Inside_Node.ino]
